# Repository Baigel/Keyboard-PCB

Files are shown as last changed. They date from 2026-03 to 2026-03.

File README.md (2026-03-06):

# Keyboard-PCB
A collection of PCB keyboards that run QMK - all in various states of completion

### Changes to Make
To PCBs
 - Oscillator to C122519
- Oscillator Load Caps to 20pF (including lcsc)
- Fix LEDs LCSC code to be correct (make sure it is C5149201)
- CC pins on USB C should be 5.1k
- Add lcsc C5156480 to sockets
- USB C to C2927038
- Change all diodes to C5345962
- Make sure Ctrl then Win then Alt
- Change Fn to Win

To Firmware:
 - Add separate firmware for different boards where relevatn
 - Add MacOS firmware versions

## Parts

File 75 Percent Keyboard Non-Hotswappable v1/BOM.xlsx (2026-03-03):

Part | Description | Units/Packet | Cost (AUD)/Packet | Shipping (AUD) | Total Cost/Packet | Unit Cost | Units/Keyboard | Cost/Keyboard | Link
PCB (112x290) | Cost of Manufacture (without assembly) | 20 | $79.850 | $55.020 | $134.87 | $6.74 | 1 | $6.74 | JLCPCB
LEDs |  | 2000 | $149.480 | $0.000 | $149.48 | $0.07 | 84 | $6.28 | https://www.aliexpress.com/item/1005004212435986.html?scm_id=1007.40050.362094.0&scm-url=1007.40050.362094.0
Switch Sockets |  | 110 | $16.650 | $1.170 | $17.82 | $0.16 | 84 | $13.61 | https://www.aliexpress.com/item/1005004290562374.html?scm_id=1007.40050.362094.0&scm-url=1007.40050.362094.0
Atmega32U4 |  | 10 | $15.150 | $0.000 | $15.15 | $1.52 | 1 | $1.52 | https://www.aliexpress.com/item/1005006140642474.html?curPageLogUid=EeYLnAB3qvgj
USB C connector |  | 1 | $0.250 | $0.000 | $0.25 | $0.25 | 1 | $0.25 | https://www.lcsc.com/product-detail/USB-Type-C_Korean-Hroparts-Elec-TYPE-C-31-M-12_C165948.html
Oscillator |  | 1 | $0.250 | $0.000 | $0.25 | $0.25 | 1 | $0.25 | https://www.lcsc.com/product-detail/Crystals_SST-S503220M20PF10PPM2P_C7568738.html
Total Cost of Board |  |  |  |  | $317.82 |  |  | $28.64

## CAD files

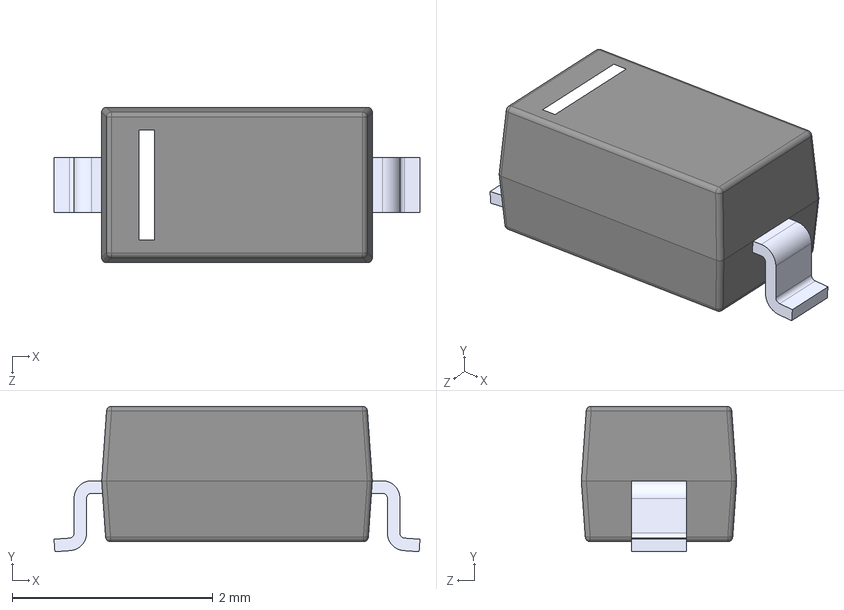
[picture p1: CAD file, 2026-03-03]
Test-Board/SymbolsAndFootprints/1N4148-7/1N4148W-7.step
3.65 x 1.45 x 1.55 mm

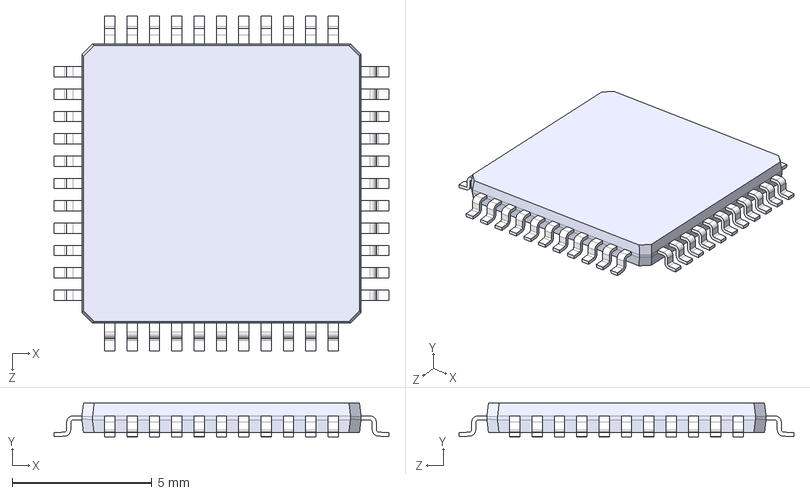
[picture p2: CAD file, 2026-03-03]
Test-Board/SymbolsAndFootprints/Atmega32U4/ATMEGA32U4-AU.step
12.0 x 1.20 x 12.0 mm

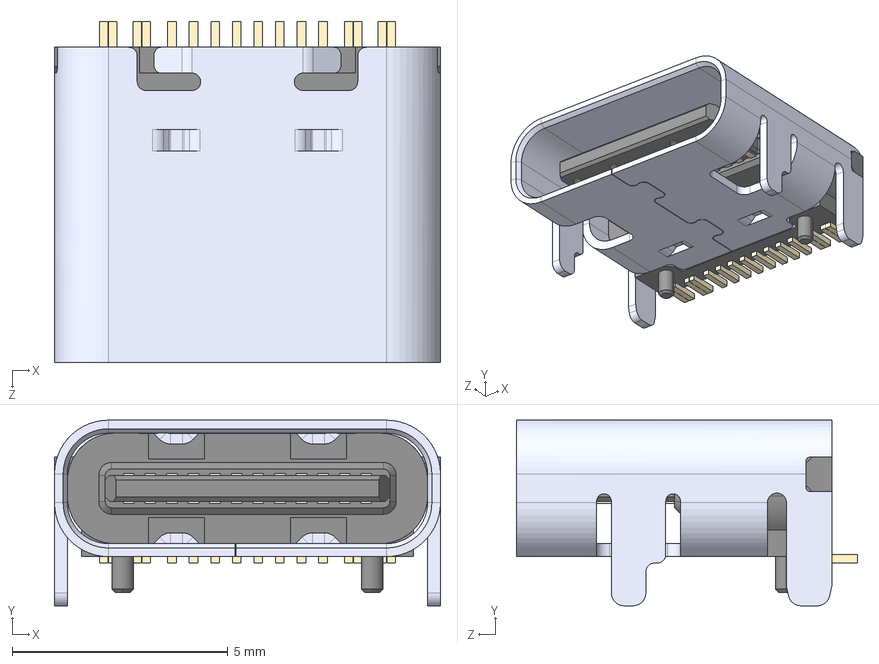
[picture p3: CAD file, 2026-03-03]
Test-Board/SymbolsAndFootprints/USB-C/TYPE-C-31-M-12.step
8.94 x 4.30 x 7.90 mm

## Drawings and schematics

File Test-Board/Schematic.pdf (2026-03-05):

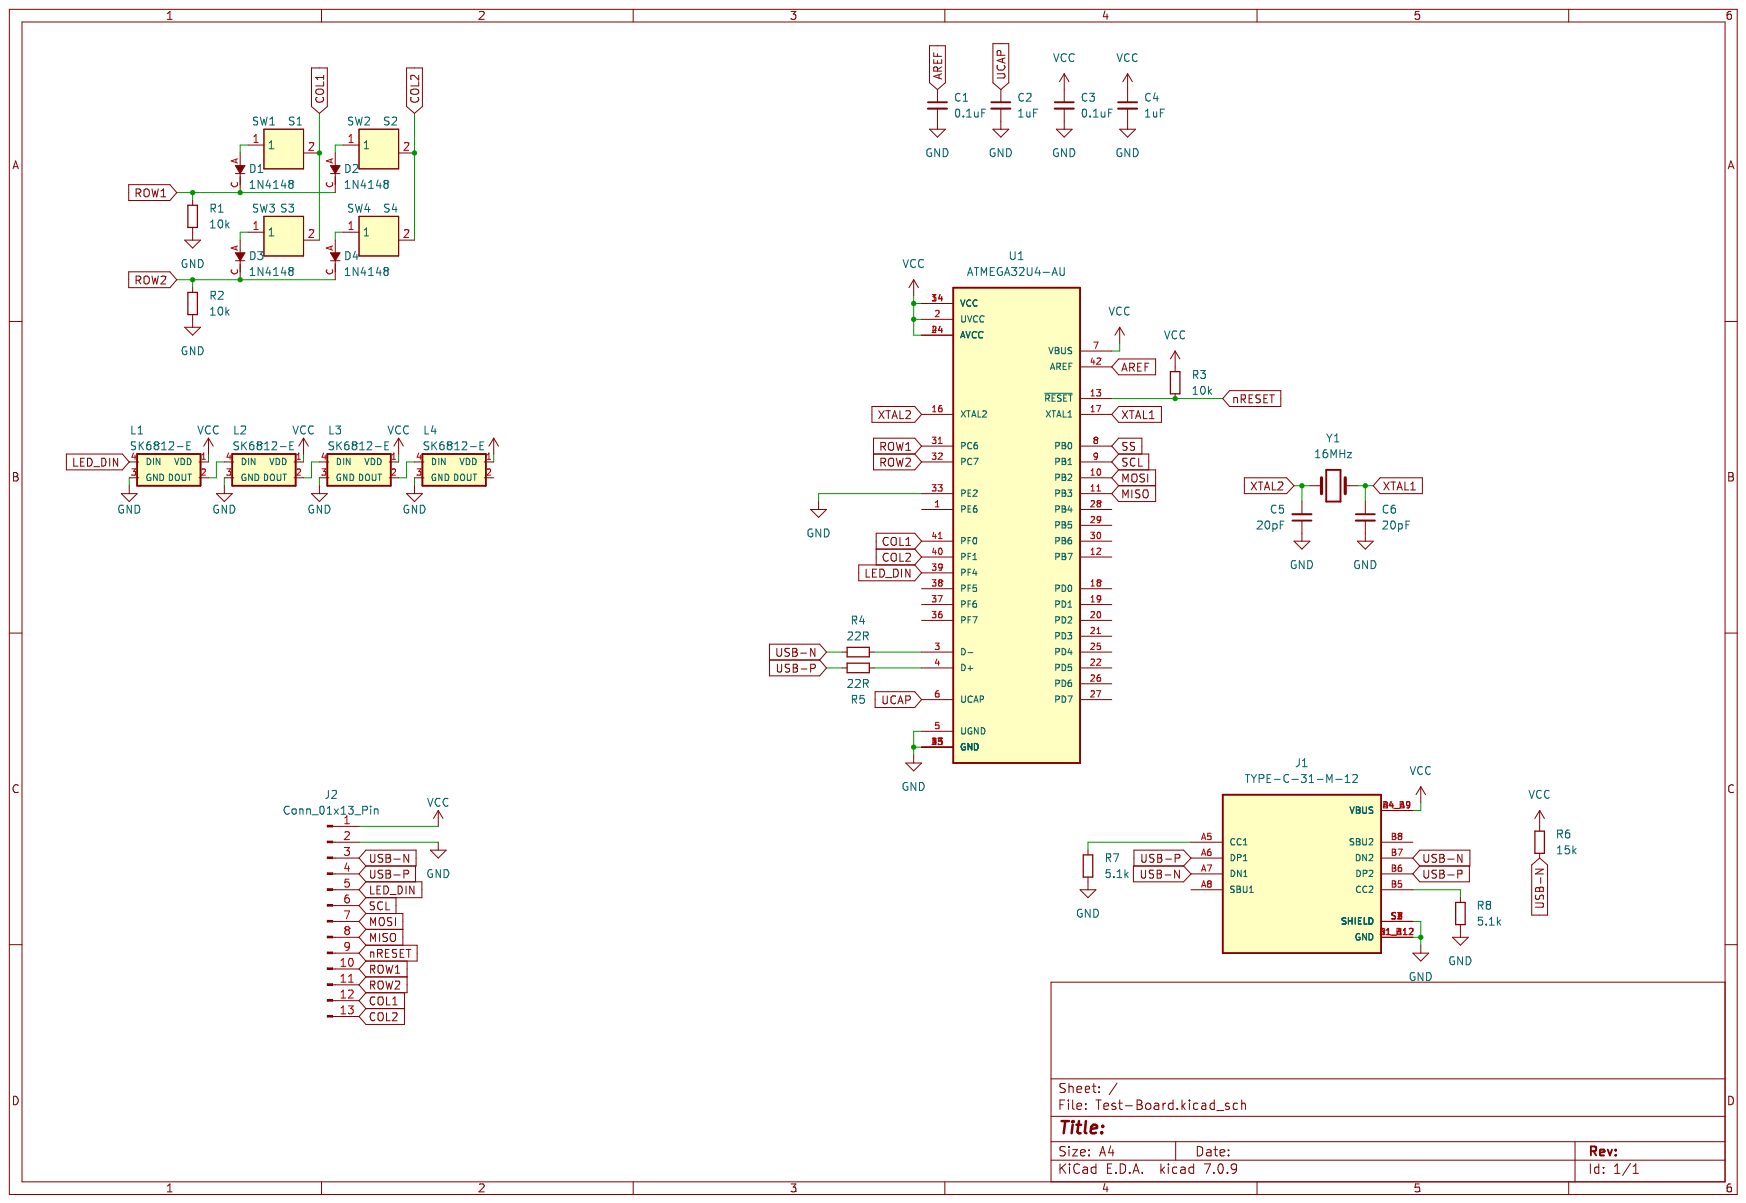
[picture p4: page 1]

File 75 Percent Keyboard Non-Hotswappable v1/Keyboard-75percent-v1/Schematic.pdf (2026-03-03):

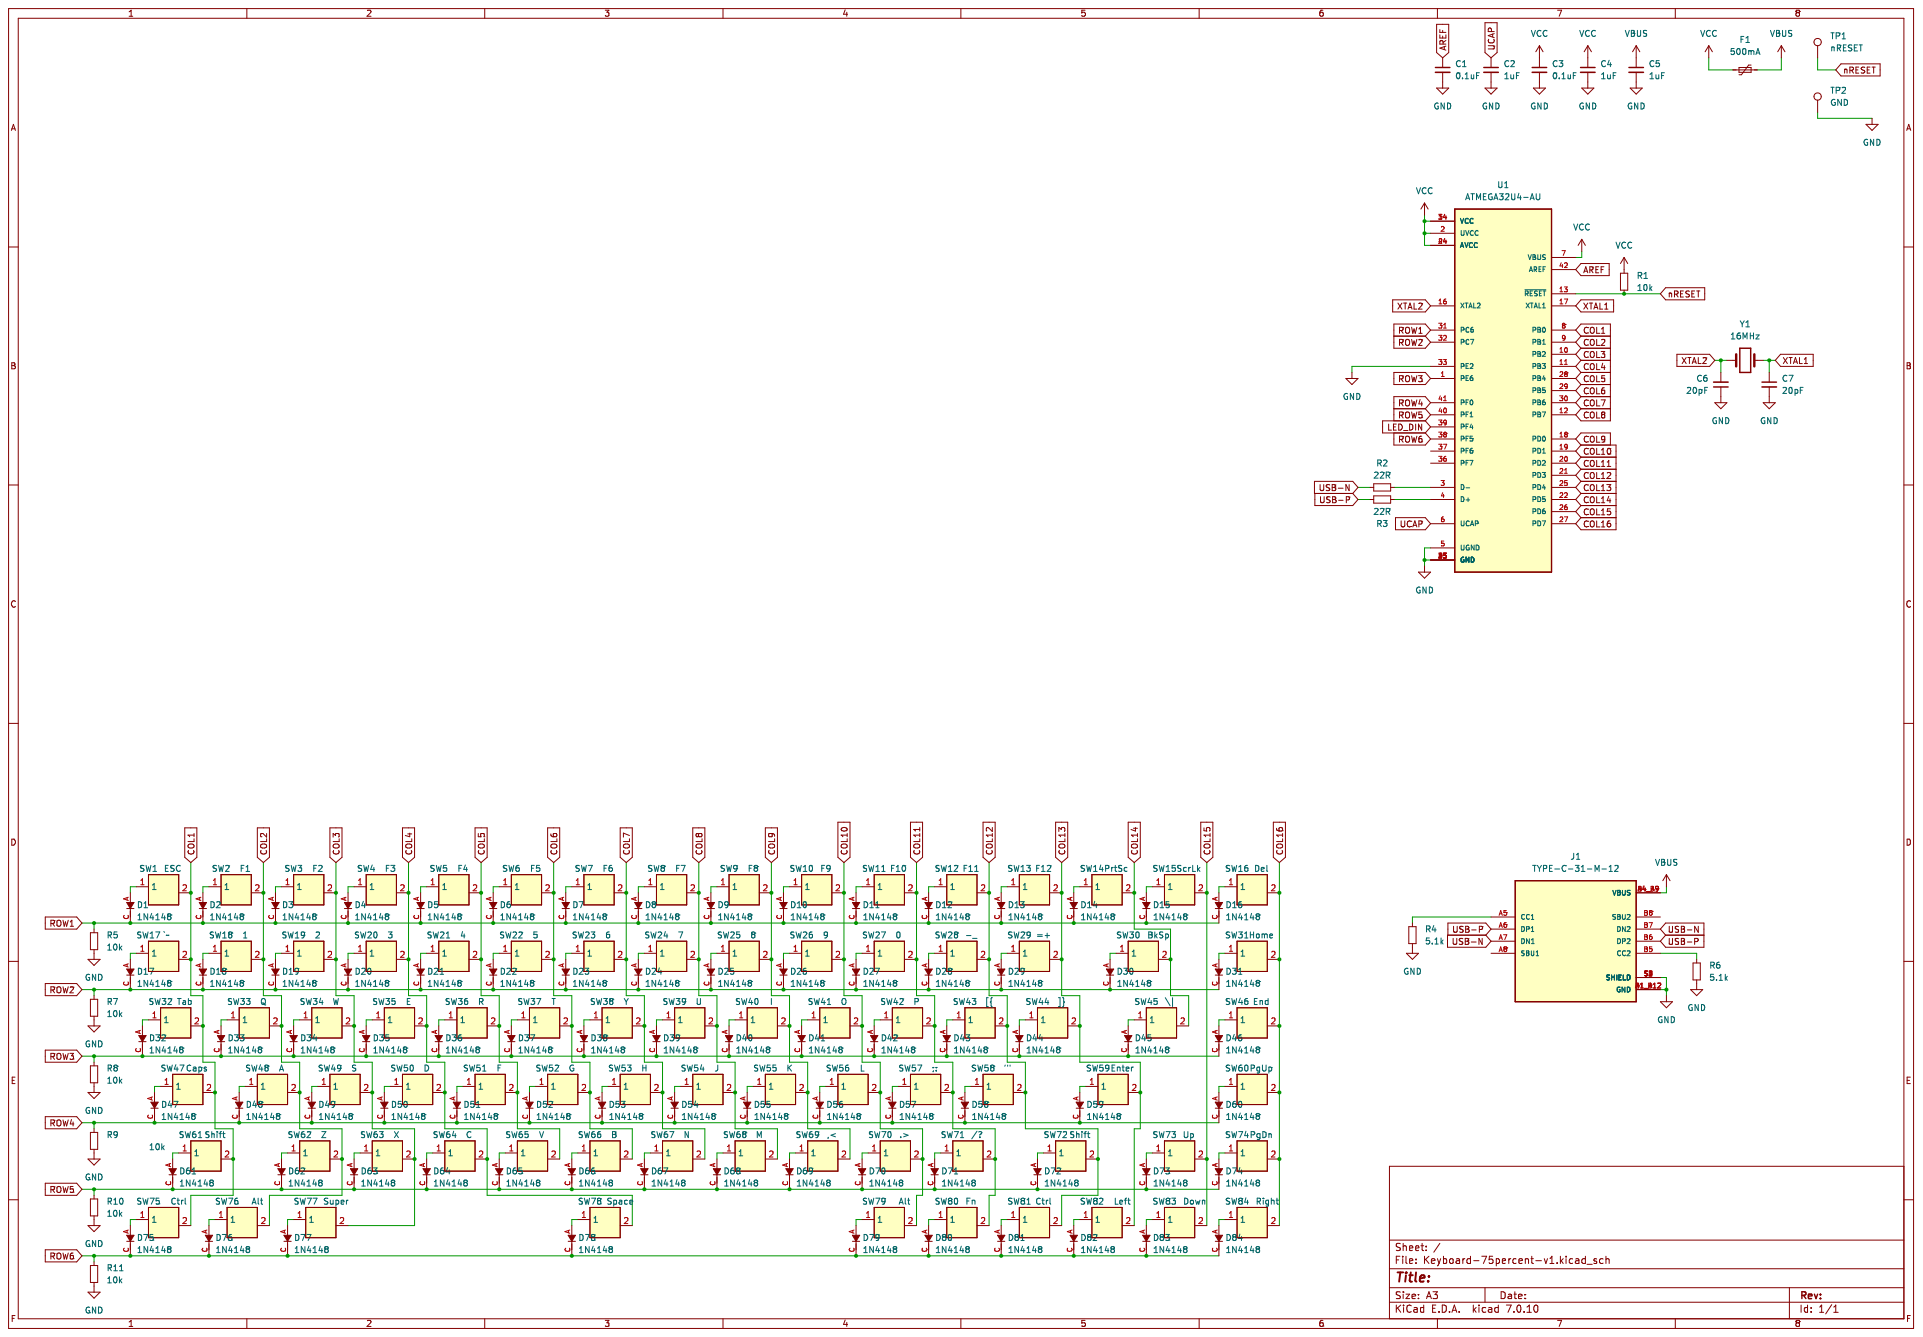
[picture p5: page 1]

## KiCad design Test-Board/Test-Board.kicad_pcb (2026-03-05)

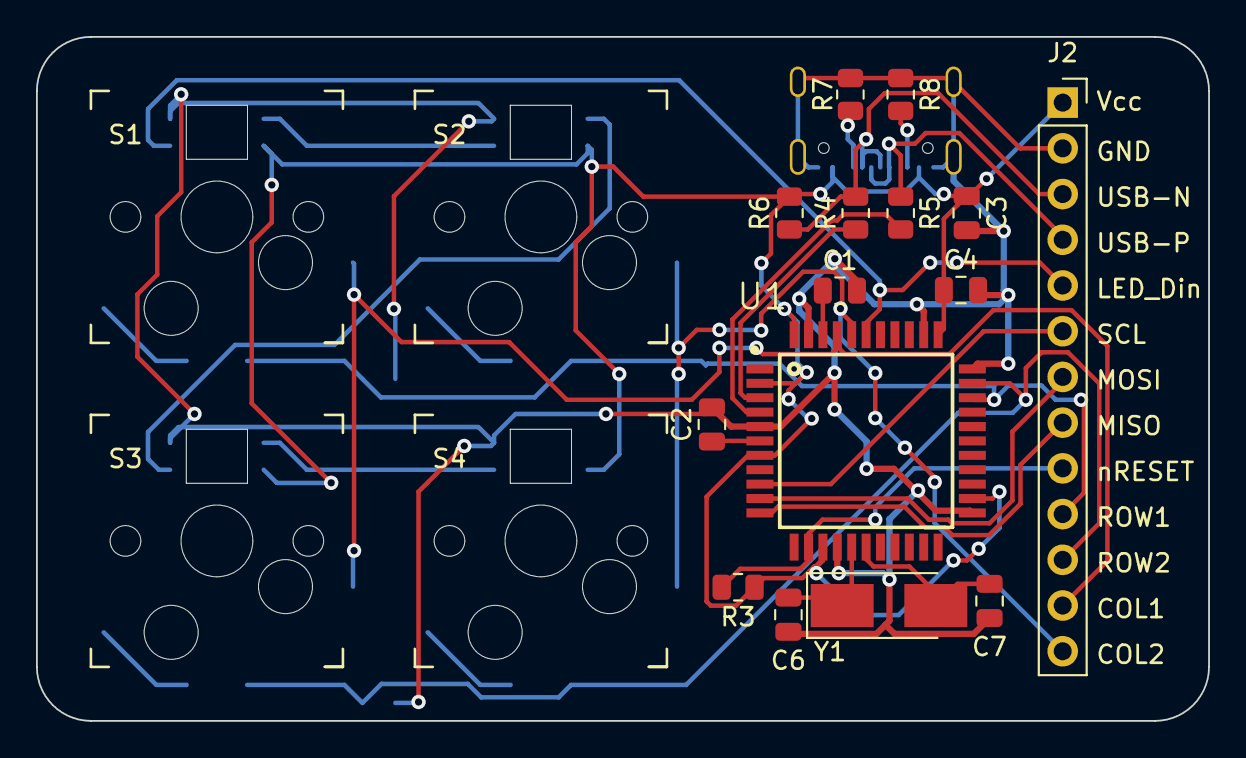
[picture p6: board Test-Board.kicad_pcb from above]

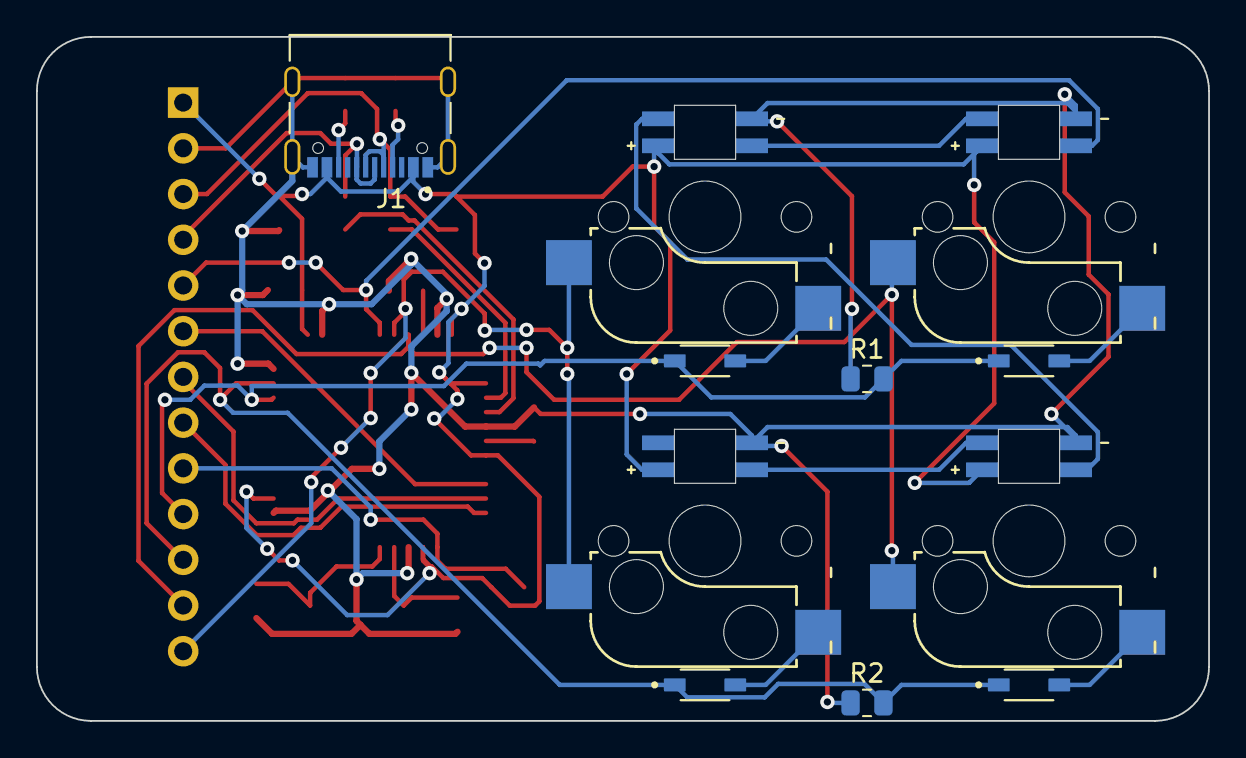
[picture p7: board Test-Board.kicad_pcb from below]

Board: 2 copper layers, 65.1 x 38.0 mm, 30 parts (11 on the bottom side), 28 nets.

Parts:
C1, C3: 0.1uF; C_0805_2012Metric
C2, C4: 1uF; C_0805_2012Metric
C6, C7: 20pF; C_0805_2012Metric
D1, D2, D3, D4: 1N4148; SOD3715X135N
J1: TYPE-C-31-M-12; HRO_TYPE-C-31-M-12
J2: Conn_01x13_Pin; PinSocket_1x13_P2.54mm_Vertical
L1, L2, L3, L4: SK6812-E; LED_SK6812-E
R1, R2, R3, R7, R8: 10k; R_0805_2012Metric
R4, R5: 22R; R_0805_2012Metric
R6: 15k; R_0805_2012Metric
SW1: S1; Kailh_socket_MX
SW2: S2; Kailh_socket_MX
SW3: S3; Kailh_socket_MX
SW4: S4; Kailh_socket_MX
U1: ATMEGA32U4-AU; QFP80P1200X1200X120-44N
Y1: 16MHz; Crystal_SMD_5032-2Pin_5.0x3.2mm_HandSoldering

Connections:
AREF: C1.1, U1.42 (AREF)
COL1: J2.12, SW1.2, SW3.2, U1.41 (PF0)
COL2: J2.13, SW2.2, SW4.2, U1.40 (PF1)
GND: C1.2, C2.2, C3.2, C4.2, C6.1, C7.2, J1.A1_B12 (GND), J1.B1_A12 (GND), J1.S1 (SHIELD), J1.S2 (SHIELD), J1.S3 (SHIELD), J1.S4 (SHIELD), J2.2, L1.3 (GND), L2.3 (GND), L3.3 (GND), L4.3 (GND), R1.1, R2.1, R7.1, R8.1, U1.5 (UGND), U1.15 (GND), U1.23 (GND), U1.33 (PE2), U1.35 (GND), U1.43 (GND)
LED_DIN: J2.5, L1.4 (DIN), U1.39 (PF4)
MISO: J2.8, U1.11 (PB3)
MOSI: J2.7, U1.10 (PB2)
unnamed: D1.A, SW1.1
unnamed: D2.A, SW2.1
unnamed: D3.A, SW3.1
unnamed: D4.A, SW4.1
unnamed: J1.A5 (CC1), R7.2
unnamed: J1.B5 (CC2), R8.2
unnamed: L1.2 (DOUT), L2.4 (DIN)
unnamed: L2.2 (DOUT), L3.4 (DIN)
unnamed: L3.2 (DOUT), L4.4 (DIN)
unnamed: R5.1, U1.4 (D+)
unnamed: R4.1, U1.3 (D-)
ROW1: D1.C, D2.C, J2.10, R1.2, U1.31 (PC6)
ROW2: D3.C, D4.C, J2.11, R2.2, U1.32 (PC7)
SCL: J2.6, U1.9 (PB1)
UCAP: C2.1, U1.6 (UCAP)
USB-N: J1.A7 (DN1), J1.B7 (DN2), J2.3, R4.2, R6.1
USB-P: J1.A6 (DP1), J1.B6 (DP2), J2.4, R5.2
VCC: C3.1, C4.1, J1.A4_B9 (VBUS), J1.B4_A9 (VBUS), J2.1, L1.1 (VDD), L2.1 (VDD), L3.1 (VDD), L4.1 (VDD), R3.1, R6.2, U1.2 (UVCC), U1.7 (VBUS), U1.14 (VCC), U1.24 (AVCC), U1.34 (VCC), U1.44 (AVCC)
XTAL1: C7.1, U1.17 (XTAL1), Y1.2
XTAL2: C6.2, U1.16 (XTAL2), Y1.1
nRESET: J2.9, R3.2, U1.13 (~RESET)

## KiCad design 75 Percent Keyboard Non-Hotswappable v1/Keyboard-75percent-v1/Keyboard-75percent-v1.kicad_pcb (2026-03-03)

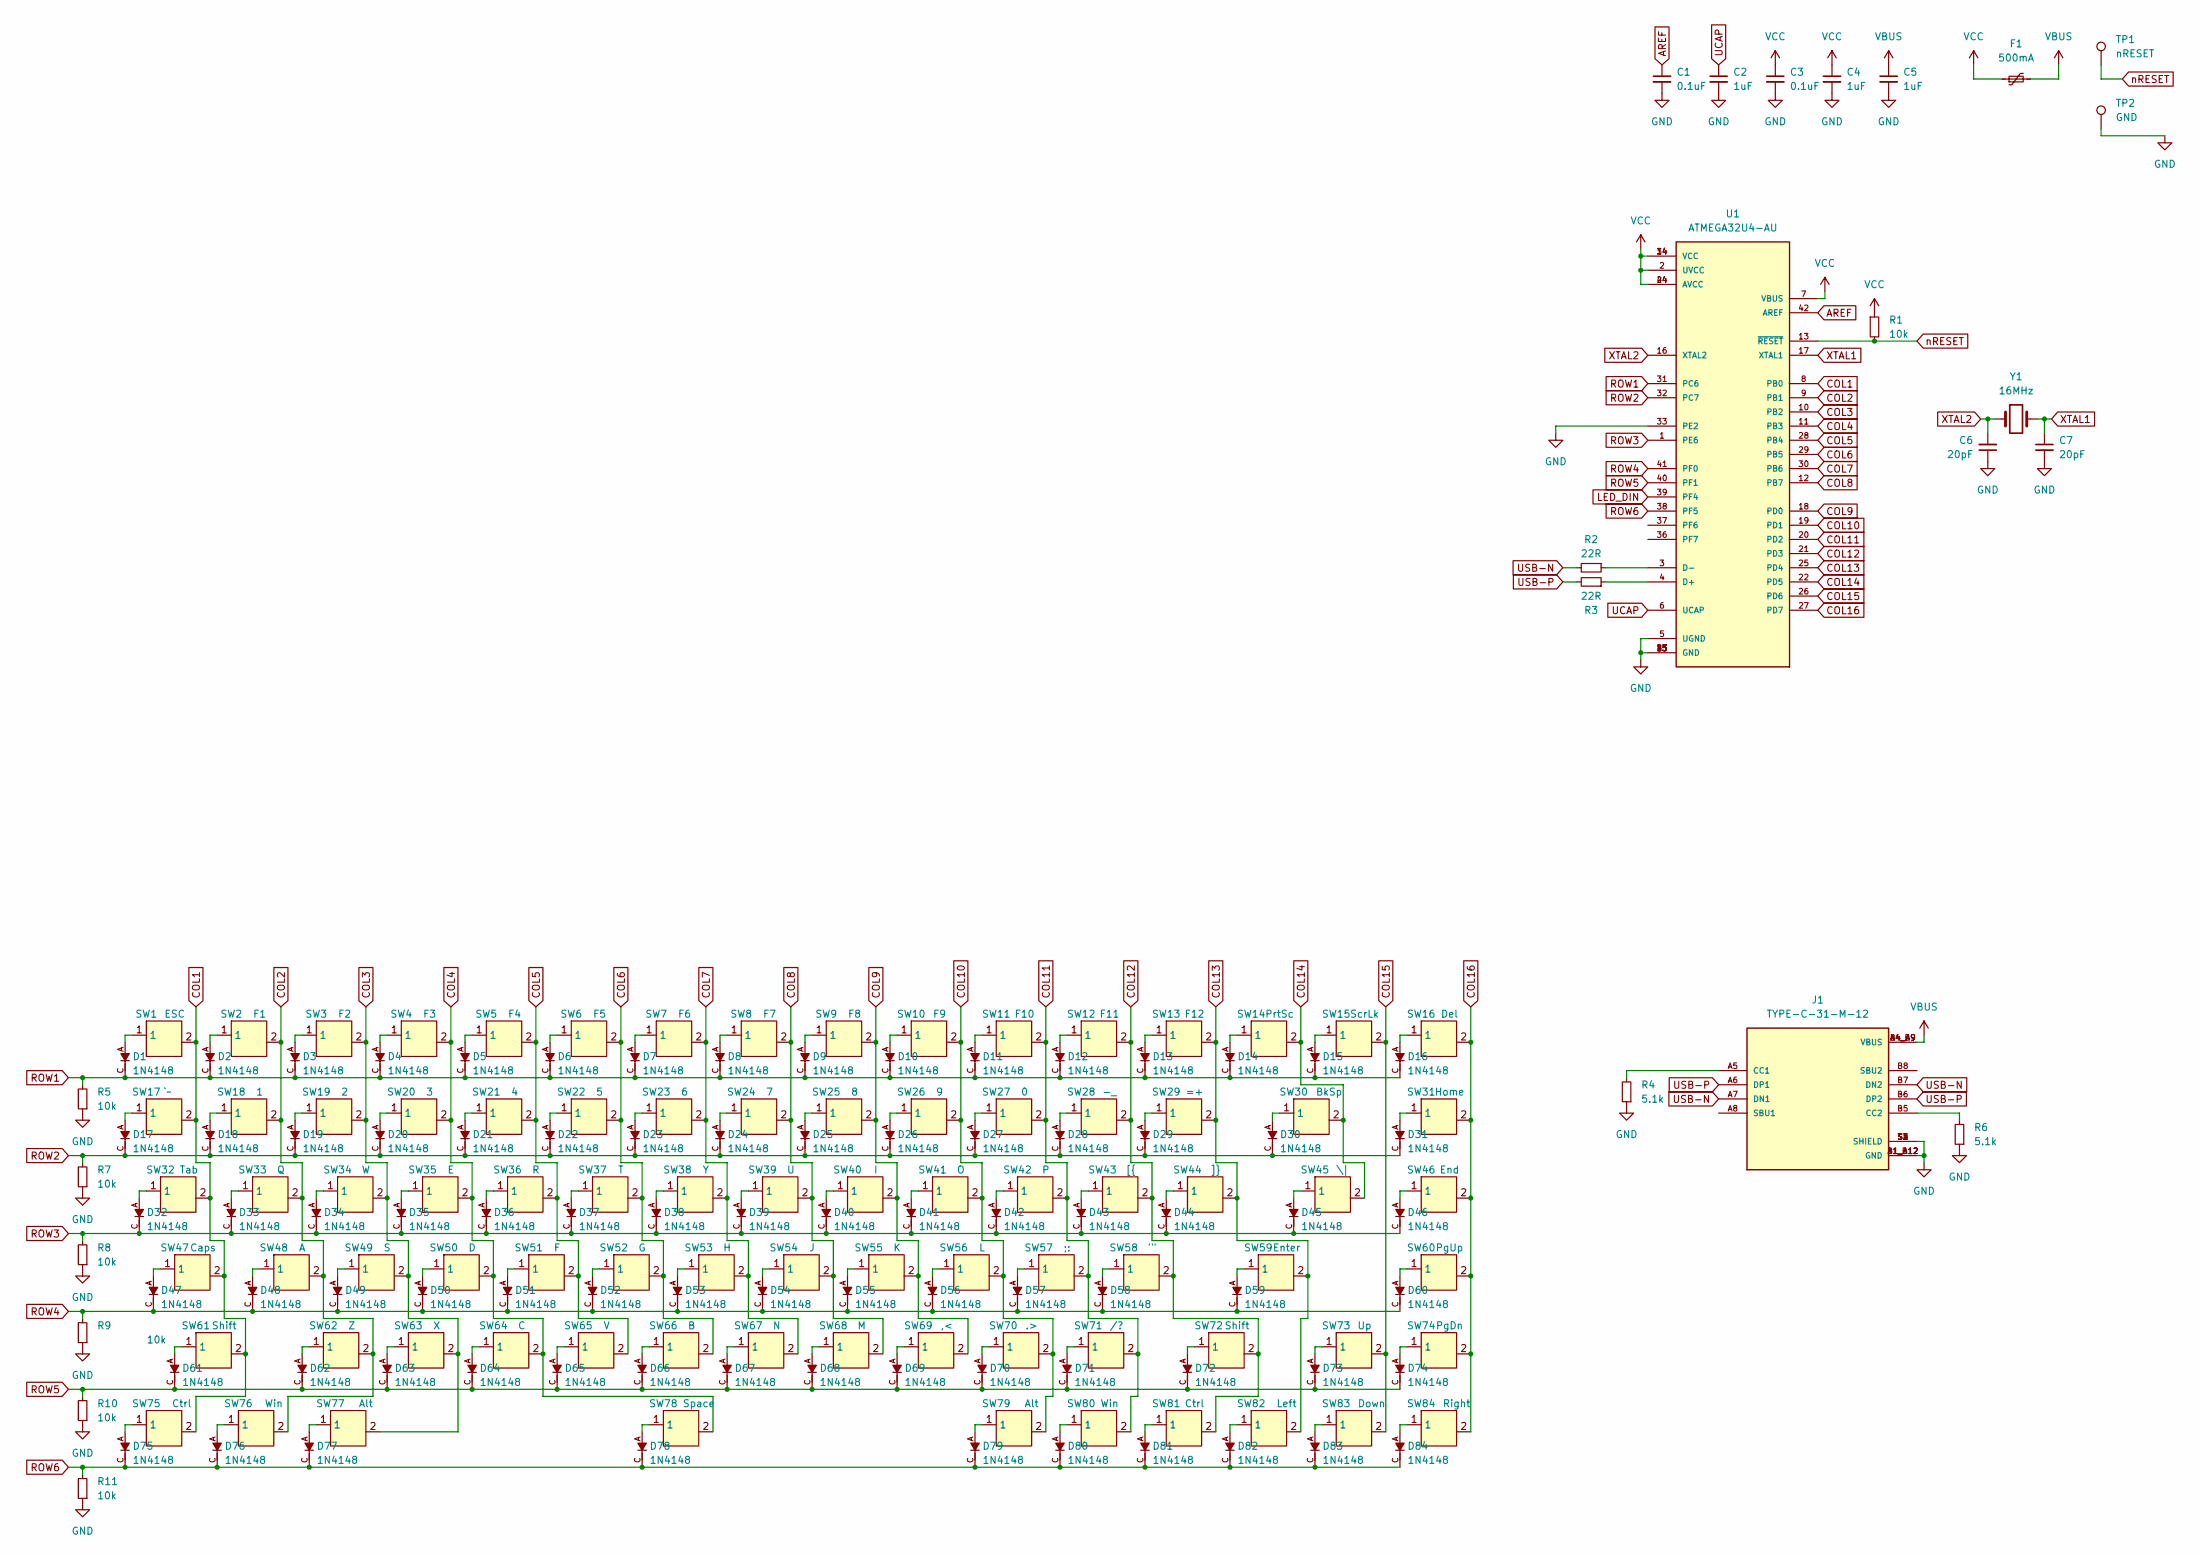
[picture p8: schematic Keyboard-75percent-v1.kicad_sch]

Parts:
C1, C3: 0.1uF; C_0805_2012Metric; LCSC C476766
C2, C4, C5: 1uF; C_0805_2012Metric; LCSC C152857
C6, C7: 20pF; C_0805_2012Metric; LCSC C2209222
D1, D2, D3, D4, D5, D6, D7, D8, D9, D10, D11, D12, D13, D14, D15, D16, D17, D18, D19, D20, D21, D22, D23, D24, D25, D26, D27, D28, D29, D30, D31, D32, D33, D34, D35, D36, D37, D38, D39, D40, D41, D42, D43, D44, D45, D46, D47, D48, D49, D50, D51, D52, D53, D54, D55, D56, D57, D58, D59, D60, D61, D62, D63, D64, D65, D66, D67, D68, D69, D70, D71, D72, D73, D74, D75, D76, D77, D78, D79, D80, D81, D82, D83, D84: 1N4148; SOD3715X135N; PARTREV 28-2; LCSC C5345962
F1: 500mA; R_0805_2012Metric_Pad1.20x1.40mm_HandSolder; LCSC C2649565
J1: TYPE-C-31-M-12; HRO_TYPE-C-31-M-12; PARTREV 2020.12.08; LCSC C2927038
R1, R5, R7, R8, R9, R10, R11: 10k; R_0805_2012Metric; LCSC C2075621
R2, R3: 22R; R_0805_2012Metric; LCSC C4349165
R4, R6: 5.1k; R_0805_2012Metric; LCSC C2079038
SW1: ESC; SW_Cherry_MX_1.00u_PCB
SW2: F1; SW_Cherry_MX_1.00u_PCB
SW3: F2; SW_Cherry_MX_1.00u_PCB
SW4: F3; SW_Cherry_MX_1.00u_PCB
SW5: F4; SW_Cherry_MX_1.00u_PCB
SW6: F5; SW_Cherry_MX_1.00u_PCB
SW7: F6; SW_Cherry_MX_1.00u_PCB
SW8: F7; SW_Cherry_MX_1.00u_PCB
SW9: F8; SW_Cherry_MX_1.00u_PCB
SW10: F9; SW_Cherry_MX_1.00u_PCB
SW11: F10; SW_Cherry_MX_1.00u_PCB
SW12: F11; SW_Cherry_MX_1.00u_PCB
SW13: F12; SW_Cherry_MX_1.00u_PCB
SW14: PrtSc; SW_Cherry_MX_1.00u_PCB
SW15: ScrLk; SW_Cherry_MX_1.00u_PCB
SW16: Del; SW_Cherry_MX_1.00u_PCB
SW17: `~; SW_Cherry_MX_1.00u_PCB
SW18: 1; SW_Cherry_MX_1.00u_PCB
SW19: 2; SW_Cherry_MX_1.00u_PCB
SW20: 3; SW_Cherry_MX_1.00u_PCB
SW21: 4; SW_Cherry_MX_1.00u_PCB
SW22: 5; SW_Cherry_MX_1.00u_PCB
SW23: 6; SW_Cherry_MX_1.00u_PCB
SW24: 7; SW_Cherry_MX_1.00u_PCB
SW25: 8; SW_Cherry_MX_1.00u_PCB
SW26: 9; SW_Cherry_MX_1.00u_PCB
SW27: 0; SW_Cherry_MX_1.00u_PCB
SW28: -_; SW_Cherry_MX_1.00u_PCB
SW29: =+; SW_Cherry_MX_1.00u_PCB
SW30: BkSp; SW_Cherry_MX_2.00u_PCB
SW31: Home; SW_Cherry_MX_1.00u_PCB
SW32: Tab; SW_Cherry_MX_1.50u_PCB
SW33: Q; SW_Cherry_MX_1.00u_PCB
SW34: W; SW_Cherry_MX_1.00u_PCB
SW35: E; SW_Cherry_MX_1.00u_PCB
SW36: R; SW_Cherry_MX_1.00u_PCB
SW37: T; SW_Cherry_MX_1.00u_PCB
SW38: Y; SW_Cherry_MX_1.00u_PCB
SW39: U; SW_Cherry_MX_1.00u_PCB
SW40: I; SW_Cherry_MX_1.00u_PCB
SW41: O; SW_Cherry_MX_1.00u_PCB
SW42: P; SW_Cherry_MX_1.00u_PCB
SW43: [{; SW_Cherry_MX_1.00u_PCB
SW44: ]}; SW_Cherry_MX_1.00u_PCB
SW45: \|; SW_Cherry_MX_1.50u_PCB
SW46: End; SW_Cherry_MX_1.00u_PCB
SW47: Caps; SW_Cherry_MX_1.75u_PCB
SW48: A; SW_Cherry_MX_1.00u_PCB
SW49: S; SW_Cherry_MX_1.00u_PCB
SW50: D; SW_Cherry_MX_1.00u_PCB
SW51: F; SW_Cherry_MX_1.00u_PCB
SW52: G; SW_Cherry_MX_1.00u_PCB
SW53: H; SW_Cherry_MX_1.00u_PCB
SW54: J; SW_Cherry_MX_1.00u_PCB
SW55: K; SW_Cherry_MX_1.00u_PCB
SW56: L; SW_Cherry_MX_1.00u_PCB
SW57: ;:; SW_Cherry_MX_1.00u_PCB
SW58: '"; SW_Cherry_MX_1.00u_PCB
SW59: Enter; SW_Cherry_MX_2.25u_PCB
SW60: PgUp; SW_Cherry_MX_1.00u_PCB
SW61: Shift; SW_Cherry_MX_2.25u_PCB
SW62: Z; SW_Cherry_MX_1.00u_PCB
SW63: X; SW_Cherry_MX_1.00u_PCB
SW64: C; SW_Cherry_MX_1.00u_PCB
SW65: V; SW_Cherry_MX_1.00u_PCB
SW66: B; SW_Cherry_MX_1.00u_PCB
SW67: N; SW_Cherry_MX_1.00u_PCB
SW68: M; SW_Cherry_MX_1.00u_PCB
SW69: ,<; SW_Cherry_MX_1.00u_PCB
SW70: .>; SW_Cherry_MX_1.00u_PCB
SW71: /?; SW_Cherry_MX_1.00u_PCB
SW72: Shift; SW_Cherry_MX_1.75u_PCB
SW73: Up; SW_Cherry_MX_1.00u_PCB
SW74: PgDn; SW_Cherry_MX_1.00u_PCB
SW75: Ctrl; SW_Cherry_MX_1.25u_PCB
SW76: Win; SW_Cherry_MX_1.25u_PCB
SW77: Alt; SW_Cherry_MX_1.25u_PCB
SW78: Space; SW_Cherry_MX_6.25u_PCB
SW79: Alt; SW_Cherry_MX_1.00u_PCB
SW80: Win; SW_Cherry_MX_1.00u_PCB
SW81: Ctrl; SW_Cherry_MX_1.00u_PCB
SW82: Left; SW_Cherry_MX_1.00u_PCB
SW83: Down; SW_Cherry_MX_1.00u_PCB
SW84: Right; SW_Cherry_MX_1.00u_PCB
TP1: nRESET; TestPoint_Pad_D2.0mm
TP2: GND; TestPoint_Pad_D2.0mm
U1: ATMEGA32U4-AU; QFP80P1200X1200X120-44N
Y1: 16MHz; Crystal_SMD_5032-2Pin_5.0x3.2mm_HandSoldering; LCSC C122519

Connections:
AREF: C1.1, U1.42 (AREF)
COL1: SW1.2, SW17.2, SW32.2, SW47.2, SW61.2, SW75.2, U1.8 (PB0)
COL2: SW2.2, SW18.2, SW33.2, SW48.2, SW62.2, SW76.2, U1.9 (PB1)
COL3: SW3.2, SW19.2, SW34.2, SW49.2, SW63.2, SW77.2, U1.10 (PB2)
COL4: SW4.2, SW20.2, SW35.2, SW50.2, SW64.2, SW78.2, U1.11 (PB3)
COL5: SW5.2, SW21.2, SW36.2, SW51.2, SW65.2, U1.28 (PB4)
COL6: SW6.2, SW22.2, SW37.2, SW52.2, SW66.2, U1.29 (PB5)
COL7: SW7.2, SW23.2, SW38.2, SW53.2, SW67.2, U1.30 (PB6)
COL8: SW8.2, SW24.2, SW39.2, SW54.2, SW68.2, U1.12 (PB7)
COL9: SW9.2, SW25.2, SW40.2, SW55.2, SW69.2, U1.18 (PD0)
COL10: SW10.2, SW26.2, SW41.2, SW56.2, SW70.2, SW79.2, U1.19 (PD1)
COL11: SW11.2, SW27.2, SW42.2, SW57.2, SW71.2, SW80.2, U1.20 (PD2)
COL12: SW12.2, SW28.2, SW43.2, SW58.2, SW72.2, SW81.2, U1.21 (PD3)
COL13: SW13.2, SW29.2, SW44.2, SW59.2, SW82.2, U1.25 (PD4)
COL14: SW14.2, SW30.2, SW45.2, U1.22 (PD5)
COL15: SW15.2, SW73.2, SW83.2, U1.26 (PD6)
COL16: SW16.2, SW31.2, SW46.2, SW60.2, SW74.2, SW84.2, U1.27 (PD7)
GND: C1.2, C2.2, C3.2, C4.2, C5.2, C6.1, C7.2, J1.A1_B12 (GND), J1.B1_A12 (GND), J1.S1 (SHIELD), J1.S2 (SHIELD), J1.S3 (SHIELD), J1.S4 (SHIELD), R4.1, R5.1, R6.1, R7.1, R8.1, R9.1, R10.1, R11.1, TP2.1, U1.5 (UGND), U1.15 (GND), U1.23 (GND), U1.33 (PE2), U1.35 (GND), U1.43 (GND)
LED_DIN: U1.39 (PF4)
unnamed: D1.A, SW1.1
unnamed: D2.A, SW2.1
unnamed: D3.A, SW3.1
unnamed: D4.A, SW4.1
unnamed: D5.A, SW5.1
unnamed: D6.A, SW6.1
unnamed: D7.A, SW7.1
unnamed: D8.A, SW8.1
unnamed: D9.A, SW9.1
unnamed: D10.A, SW10.1
unnamed: D11.A, SW11.1
unnamed: D12.A, SW12.1
unnamed: D13.A, SW13.1
unnamed: D14.A, SW14.1
unnamed: D15.A, SW15.1
unnamed: D16.A, SW16.1
unnamed: D17.A, SW17.1
unnamed: D18.A, SW18.1
unnamed: D19.A, SW19.1
unnamed: D20.A, SW20.1
unnamed: D21.A, SW21.1
unnamed: D22.A, SW22.1
unnamed: D23.A, SW23.1
unnamed: D24.A, SW24.1
unnamed: D25.A, SW25.1
unnamed: D26.A, SW26.1
unnamed: D27.A, SW27.1
unnamed: D28.A, SW28.1
unnamed: D29.A, SW29.1
unnamed: D30.A, SW30.1
unnamed: D31.A, SW31.1
unnamed: D32.A, SW32.1
unnamed: D33.A, SW33.1
unnamed: D34.A, SW34.1
unnamed: D35.A, SW35.1
unnamed: D36.A, SW36.1
unnamed: D37.A, SW37.1
unnamed: D38.A, SW38.1
unnamed: D39.A, SW39.1
unnamed: D40.A, SW40.1
unnamed: D41.A, SW41.1
unnamed: D42.A, SW42.1
unnamed: D43.A, SW43.1
unnamed: D44.A, SW44.1
unnamed: D45.A, SW45.1
unnamed: D46.A, SW46.1
unnamed: D47.A, SW47.1
unnamed: D48.A, SW48.1
unnamed: D49.A, SW49.1
unnamed: D50.A, SW50.1
unnamed: D51.A, SW51.1
unnamed: D52.A, SW52.1
unnamed: D53.A, SW53.1
unnamed: D54.A, SW54.1
unnamed: D55.A, SW55.1
unnamed: D56.A, SW56.1
unnamed: D57.A, SW57.1
unnamed: D58.A, SW58.1
unnamed: D59.A, SW59.1
unnamed: D60.A, SW60.1
unnamed: D61.A, SW61.1
unnamed: D62.A, SW62.1
unnamed: D63.A, SW63.1
unnamed: D64.A, SW64.1
unnamed: D65.A, SW65.1
unnamed: D66.A, SW66.1
unnamed: D67.A, SW67.1
unnamed: D68.A, SW68.1
unnamed: D69.A, SW69.1
unnamed: D70.A, SW70.1
unnamed: D71.A, SW71.1
unnamed: D72.A, SW72.1
unnamed: D73.A, SW73.1
unnamed: D74.A, SW74.1
unnamed: D75.A, SW75.1
unnamed: D76.A, SW76.1
unnamed: D77.A, SW77.1
unnamed: D78.A, SW78.1
unnamed: D79.A, SW79.1
unnamed: D80.A, SW80.1
unnamed: D81.A, SW81.1
unnamed: D82.A, SW82.1
unnamed: D83.A, SW83.1
unnamed: D84.A, SW84.1
unnamed: J1.A5 (CC1), R4.2
unnamed: J1.B5 (CC2), R6.2
unnamed: R3.1, U1.4 (D+)
unnamed: R2.1, U1.3 (D-)
ROW1: D1.C, D2.C, D3.C, D4.C, D5.C, D6.C, D7.C, D8.C, D9.C, D10.C, D11.C, D12.C, D13.C, D14.C, D15.C, D16.C, R5.2, U1.31 (PC6)
ROW2: D17.C, D18.C, D19.C, D20.C, D21.C, D22.C, D23.C, D24.C, D25.C, D26.C, D27.C, D28.C, D29.C, D30.C, D31.C, R7.2, U1.32 (PC7)
ROW3: D32.C, D33.C, D34.C, D35.C, D36.C, D37.C, D38.C, D39.C, D40.C, D41.C, D42.C, D43.C, D44.C, D45.C, D46.C, R8.2, U1.1 (PE6)
ROW4: D47.C, D48.C, D49.C, D50.C, D51.C, D52.C, D53.C, D54.C, D55.C, D56.C, D57.C, D58.C, D59.C, D60.C, R9.2, U1.41 (PF0)
ROW5: D61.C, D62.C, D63.C, D64.C, D65.C, D66.C, D67.C, D68.C, D69.C, D70.C, D71.C, D72.C, D73.C, D74.C, R10.2, U1.40 (PF1)
ROW6: D75.C, D76.C, D77.C, D78.C, D79.C, D80.C, D81.C, D82.C, D83.C, D84.C, R11.2, U1.38 (PF5)
UCAP: C2.1, U1.6 (UCAP)
USB-N: J1.A7 (DN1), J1.B7 (DN2), R2.2
USB-P: J1.A6 (DP1), J1.B6 (DP2), R3.2
VBUS: C5.1, F1.2, J1.A4_B9 (VBUS), J1.B4_A9 (VBUS)
VCC: C3.1, C4.1, F1.1, R1.1, U1.2 (UVCC), U1.7 (VBUS), U1.14 (VCC), U1.24 (AVCC), U1.34 (VCC), U1.44 (AVCC)
XTAL1: C7.1, U1.17 (XTAL1), Y1.2
XTAL2: C6.2, U1.16 (XTAL2), Y1.1
nRESET: R1.2, TP1.1, U1.13 (~RESET)

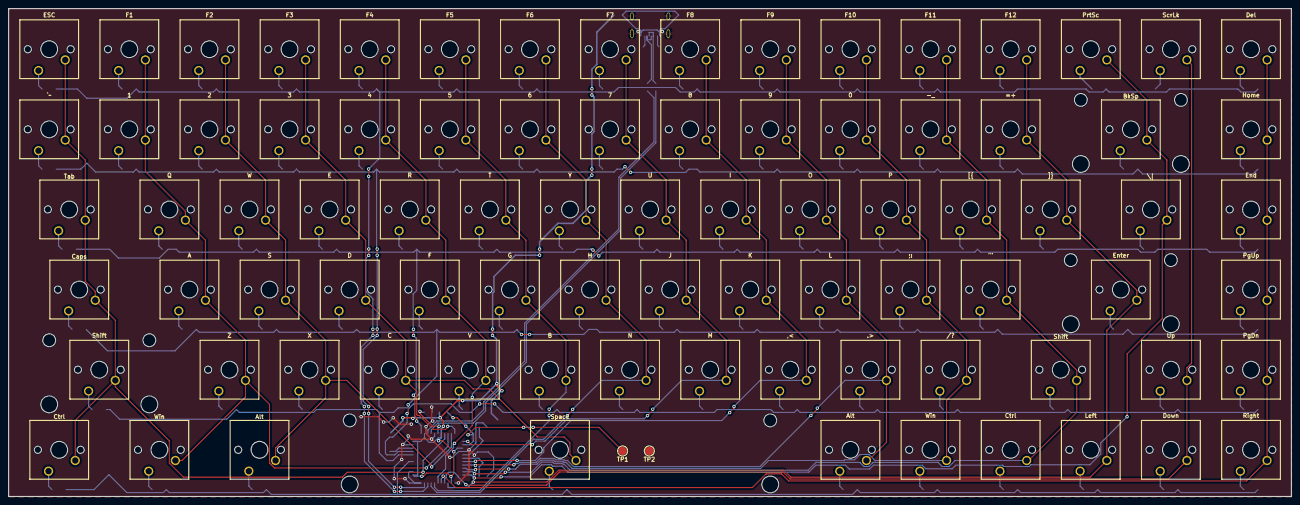
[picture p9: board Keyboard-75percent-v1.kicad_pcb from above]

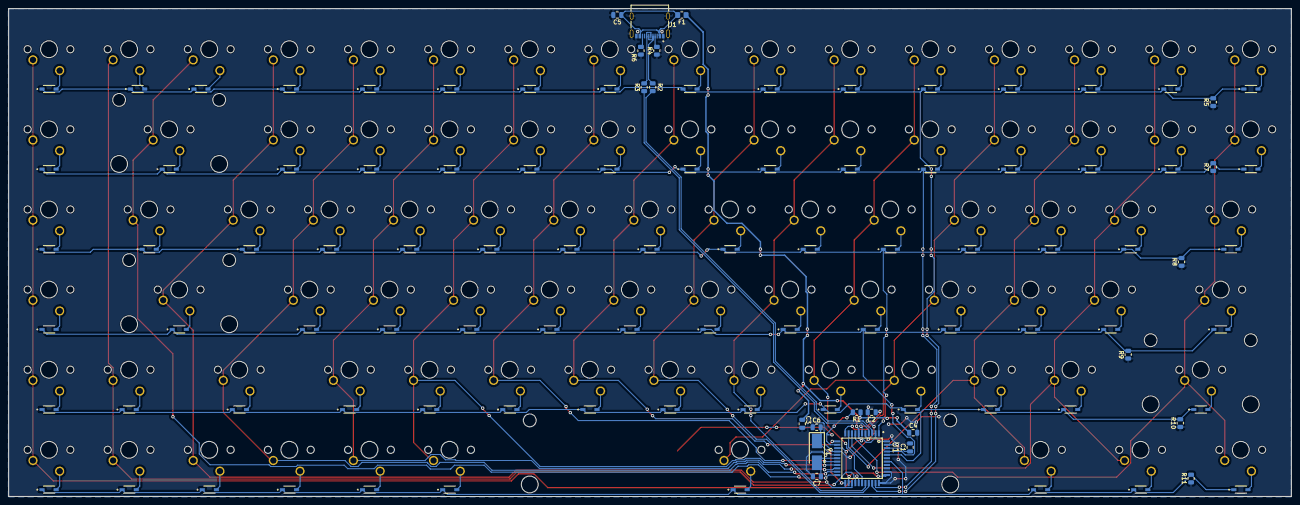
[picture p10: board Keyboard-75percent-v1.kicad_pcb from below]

Board: 2 copper layers, 305.0 x 116.0 mm, 192 parts (106 on the bottom side), 120 nets.

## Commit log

2026-03-03 initial commit with KiCad PCB files
    [1N4148W-7.step, ATMEGA32U4-AU.step, BOM.xlsx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]
2026-03-05 Added test board PCB
    [1N4148W-7.step, ATMEGA32U4-AU.step, Atmega-Test-Board.kicad_sch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]
